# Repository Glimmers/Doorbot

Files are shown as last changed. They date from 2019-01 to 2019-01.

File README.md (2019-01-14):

Doorbot -- Internet enabled doorbell discord bot
================================================

This project contains the files and schematics needed to build a raspberry-pi compatible doorbell
which will send a message to a Discord channel.

Dependencies
------------

* A Raspberry Pi running Raspbian
* The following packages

        python3
        python3-rpi.gpio
        python3-requests

* A Discord account
* A webhook set up for the discord channel you want your messages to go to. For instructions on
      setting up a webhook, visit
      https://support.discordapp.com/hc/en-us/articles/228383668-Intro-to-Webhooks

Software Installation instructions
----------------------------------

1. Download the package to your pi.

    * Via git: 

            git clone https://github.com/Glimmers/Doorbot.git doorbot

    * Via wget:

            wget https://github.com/Glimmers/Doorbot/archive/master.zip

2. Run the included `install.sh` shell script to add the requisite service user, install dependencies,
copy the files into the service user's directory, and install the systemd service.

3. Copy the example `discord.ini` file to the actual ini file, and fill out the fields inside. At a
minimum, you will need to replace all the values in the `[Doorbot]` section.

    a) If you're not using a camera, set `UseCamera = no` .

    b) If you are using a Camera, fill out the [Camera] section with the access type, hostname,
    username and password if needed, and path to get an image. For example, if the URL to get an image
    from the camera is: http://hostname/path/to/image.cgi , you'll want to set the config values as:

        [Camera]
        Protocol = http
        Host = hostname
        Path = /path/to/image.cgi

4. Enable the doorbot service
    
        sudo systemctl enable doorbot.service

5. Start the doorbot service

        sudo systemctl start doorbot.service

Hardware Installation Instructions
----------------------------------

In the Eagle Schematics directory, there are schematics in Eagle 7.x format for two variants of sense
boards. The first -- Doorbell.sch -- is a basic 1-transistor schematic. The second --
DoorbellBothRelayBJT.sch -- is the 3-transistor schematic which has better noise tolerance. For both of
these circuits, hooking up to the Pi side of the board is the same. Pin 1 goes to the +3.3 volt supply
pin of the Pi (pin 1 or pin 17). Pin 2 goes to one of the GPIO pins, typically pin 37. Pin 3 goes to
Ground (any one of pin 6, 9, 14, 20, 25, 30, 34, or 39).

* For the 1 transistor schematic, pin 1 of the relay side goes to the Normally Open pin of the
  relay. Pin 3 of the relay goes to the common side. Pin 2 is for testing, and not used for normal
  operation.

* For the 3-transistor schematic, pin one of the relay side goes to the Normally Open pin of the
  relay. Pin 2 goes to the Common pin of the relay. Pin 3 goes to the Normally Closed pin.

For hooking the relay up to the chime, typically you'll hook the coil leads so one is going to the
terminal labelled "Trans" and the other to the terminal labelled "Front". While hooking it up, you'll
want to either disconnect the doorbell transformer, or have someone watching the door to
avoid the risk of getting shocked while hooking it up.

For Testing/Development
-----------------------

The one-transistor board has a provision for testing, which is useful in developing the software for
the board. In testing, remove the board from the relay, and hook a 2N2222 or 2N3904 transistor to the
relay header, with pin 1 of the transistor corresponding to pin 1 of the socket, pin 2 of the
transistor going to pin 2 of the socket, and pin 3 going to pin 3. The test pin should go to one of the
GPIO leads of the Pi, typically pin 35.

License
-------

This project is available under the 2-clause BSD license. For details of the license, see the LICENSE file.

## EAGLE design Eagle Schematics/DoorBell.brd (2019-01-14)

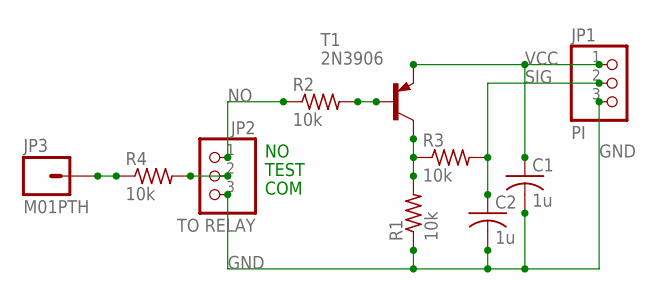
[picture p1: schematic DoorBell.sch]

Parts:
C1, C2: 1u; C025-025X050
JP1: PI; 1X03
JP2: TO RELAY; 1X03
JP3: M01PTH; 1X01
R1, R2, R3, R4: 10k; 0204/5
T1: 2N3906; TO92-EBC

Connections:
GND: C1.2, C2.2, JP1.3, JP2.3, R1.1
unnamed: R1.2, R3.1, T1.C
unnamed: R2.2, T1.B
unnamed: JP2.2, R4.2
unnamed: JP3.1, R4.1
NO: JP2.1, R2.1
SIG: C2.1, JP1.2, R3.2
VCC: C1.1, JP1.1, T1.E

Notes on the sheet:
TEST
COM

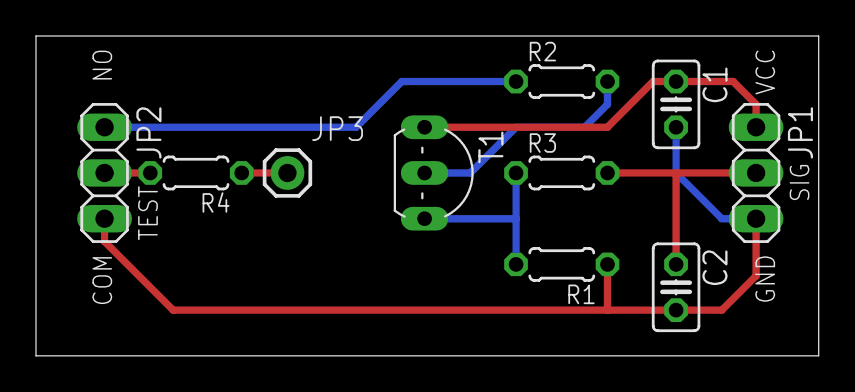
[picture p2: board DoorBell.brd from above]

Board: 2 copper layers, 43.5 x 17.8 mm, 10 parts (0 on the bottom side), 8 nets.

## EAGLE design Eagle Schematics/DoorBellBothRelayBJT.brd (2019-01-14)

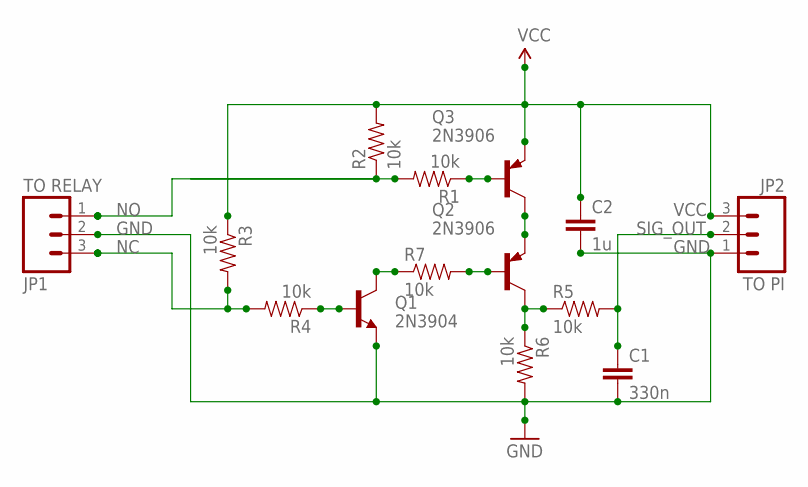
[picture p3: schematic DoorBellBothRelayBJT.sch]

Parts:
C1: 330n; CAP-PTH-SMALL-KIT
C2: 1u; CAP-PTH-SMALL-KIT
JP1: TO RELAY; 1X03_NO_SILK
JP2: TO PI; 1X03_NO_SILK
Q1: 2N3904; TO-92
Q2, Q3: 2N3906; TO92
R1, R2, R3, R4, R5, R6, R7: 10k; AXIAL-0.3EZ

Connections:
GND: C1.2, C2.2, JP1.2, JP2.1, Q1.1 (E), R6.P$2 (2)
unnamed: Q1.3 (C), R7.P$1 (1)
unnamed: Q2.2 (B), R7.P$2 (2)
unnamed: Q1.2 (B), R4.P$1 (1)
unnamed: Q3.2 (B), R1.P$1 (1)
unnamed: Q2.3 (E), Q3.1 (C)
unnamed: Q2.1 (C), R5.P$1 (1), R6.P$1 (1)
NC: JP1.3, R3.P$2 (2), R4.P$2 (2)
NO: JP1.1, R1.P$2 (2), R2.P$1 (1)
SIG_OUT: C1.1, JP2.2, R5.P$2 (2)
VCC: C2.1, JP2.3, Q3.3 (E), R2.P$2 (2), R3.P$1 (1)

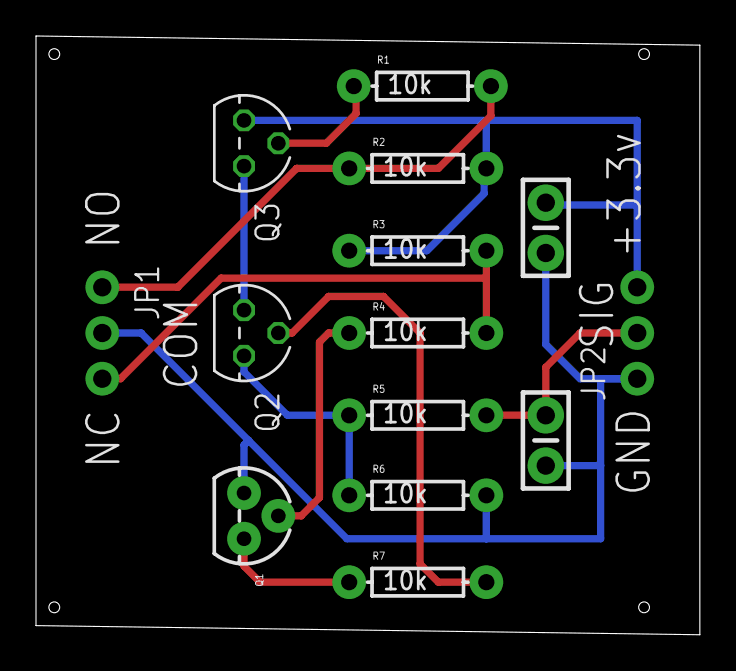
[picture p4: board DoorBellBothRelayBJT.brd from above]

Board: 2 copper layers, 36.9 x 33.3 mm, 14 parts (0 on the bottom side), 11 nets.

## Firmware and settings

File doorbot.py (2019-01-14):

#!/usr/bin/python3 -u

# Doorbot.py Copyright 2019 Kes Zerda
# 
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
import RPi.GPIO as GPIO
import os
import fcntl
import time
import syslog
import atexit
import requests
import configparser
from datetime import datetime

noalertfile = '/home/doorbot/noalert'
pidfile = '/home/doorbot/doorbot.pid'

# Pull and parse config file
config = configparser.ConfigParser()
config.read('doorbot.ini')

# Missing main section, bail
if 'Doorbot' not in config:
  raise Exception('Missing "Doorbot" section in doorbot.ini')

main_config = config['Doorbot']
use_camera = main_config.getboolean('UseCamera', False)

# We need to know what pin we're listening on
if 'sensorpin' not in main_config:
  raise Exception('Missing SensorPin definition in Doorbot section of doorbot.ini')

sensor_pin = main_config.getint('sensorpin')

if 'discordwebhook' not in main_config:
  raise Exception('Missing "DiscordWebhook" definition in Doorbot section of doorbot.ini')

discord_webhook = main_config.get('discordwebhook')
discord_uri = "https://discordapp.com/api/webhooks/" + discord_webhook

# Message to display when the bell is rung. If one's not provided, we give a generic
message = main_config.get('message', '@here Ding Dong')

# Build camera image path if we're set to use a camera
camera_image_uri=''

if use_camera:
  camera_config = config['Camera']

  # We need at least a host and a path for the camera, everything else can be either implied or skipped
  if 'host' not in camera_config:
    raise Exception('Missing "Host" definition in [Camera] section of doorbot.ini')

  if 'path' not in camera_config:
    raise Exception('Missing "Path" definition in [Camera] section of doorbot.ini')

  camera_protocol = camera_config.get('protocol', 'http')
  camera_host = camera_config.get('host')
  camera_path = camera_config.get('path')
  camera_user = camera_config.get('user', '')
  camera_pass = camera_config.get('pass', '')

  # The Requests library which we use does not support anythng but http(s)
  if (camera_protocol != 'http' and camera_protocol != 'https'):
    raise Exception('Unable to handle Protocol ' + camera_protocol + ' . Valid protocols are http or https')

  # Assemble full uri based on provided info

  camera_hostpath = camera_host + camera_path
  camera_prot = camera_protocol + '://'

  if (camera_user == ''):
    camera_image_uri = camera_prot + camera_hostpath
  elif (camera_pass == ''):
    camera_image_uri = camera_prot + camera_user + '@' + camera_hostpath
  else:
    camera_image_uri = camera_prot + camera_user + ':' + camera_pass + '@' + camera_hostpath

discord_json = """
{
    "content": "Camera view:",
    "embed": {
       "url": "attachment://doorbot.jpg"
    }
}
"""

camera_form = {
    'content':'Camera view:',
    'payload_json':discord_json
}

# Function for clearing the PID file on completion

def closePid(pidHandle):
    pidHandle.seek(0)
    pidHandle.truncate()
    fcntl.flock(pidHandle, fcntl.LOCK_UN)
    pidHandle.close()

# Setup GPIO, using pi pin numbers
GPIO.setmode(GPIO.BOARD)
GPIO.setup(sensor_pin, GPIO.IN)

# Lock the PID file to prevent multiple bot instances from running simultaneously
pid = str(os.getpid())
pidLock = open(pidfile, 'w') 
fcntl.flock(pidLock, fcntl.LOCK_EX | fcntl.LOCK_NB)
pidLock.write(pid)
pidLock.flush()
os.fsync(pidLock)

atexit.register(closePid, pidLock)

# Setup is done, start main event loop

print("Now Waiting")

while (True):
  status = GPIO.wait_for_edge(sensor_pin, GPIO.RISING, timeout=1000)
  
  if status == sensor_pin:
    time.sleep(10.0/1000)
  
    # Debounce/deglitch filter to strip out false positives 
    if GPIO.input(sensor_pin) == False :
      time.sleep(10.0/1000)
      if GPIO.input(sensor_pin) == False :
        print(str(datetime.now()) + " -- " + "Glitch. Disregarding")
        continue

    # If we're not set to alert, don't send web alert, don't get camera image 
    if os.path.isfile(noalertfile) :
      print(str(datetime.now()) + " -- " + "Bell rang, alerts disabled")
      continue

    # Send doorbell alert
    doorbell_message = { 'content':message }
    response = requests.post(discord_uri, data = doorbell_message) 

    status = response.status_code
    msg = response.text

    print(str(datetime.now()) + " -- " + str(status) + ": " + msg)

    # If we're not using the camera, go back to waiting here
    if (use_camera == False):
      time.sleep(5)
      continue

    # Get jpeg from camera
    camera_response = requests.get(camera_image_uri)
    camera_image = camera_response.content

    # Assemble camera post
    camera_message = { 'content':'Camera view:' }
    camera_files = {'file':('doorbot.jpg', camera_image, 'image/jpeg', {'Expires': '0'})}

    response = requests.post(discord_uri, data = camera_message, files = camera_files) 
    status = response.status_code
    msg = response.text

    print(str(datetime.now()) + " -- " + str(status) + ": " + msg)
    time.sleep(5)

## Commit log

2019-01-08 Replaced hardcoded value for active pin with the variable it refers to
    [doorbot.py]
2019-01-08 Minor cleanup, changed wording on some comments/error messages
    [doorbot.py]
2019-01-14 Cleared out PID file to prevent potential issues when running
    [doorbot.py]
2019-01-14 Fix code so it pulls the sensor_pin value from the config so the code starts, fix unit file so it sets the working directory properly
    [doorbot.py]
2019-01-14 Added schematics and board layout
    [DoorBellBothRelayBJT.brd, DoorBellBothRelayBJT.sch]
2019-01-14 Added basic doorbell schematic
    [DoorBell.brd, DoorBell.sch]
2019-01-14 Improved Board Labels
    [DoorBell.brd, DoorBell.sch]

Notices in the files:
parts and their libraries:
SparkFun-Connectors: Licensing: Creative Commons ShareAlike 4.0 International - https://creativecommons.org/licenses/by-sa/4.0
